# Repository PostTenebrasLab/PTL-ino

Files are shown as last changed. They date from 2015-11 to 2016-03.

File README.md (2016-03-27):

# PTL-ino

The PTL-ino (“petilino”) is a *uino-compatbile board that is fully made of easily solderable through-hole components.

You can find more general information at http://ptl-ino.com

The current Kicad file were made with Kicad 4.0.2, so please upgrade to Kicad 4 if you haven't already.
The Gerber file are there in case you simply want to order PCB directly to service like OSHPark or DirtyPCB.

If you plan to sell board based on this design, you have to remove our logo from the PCB.

PTL-ino board is licensed with Creative Common BY-SA 4.0 (https://creativecommons.org/licenses/by-sa/4.0/)

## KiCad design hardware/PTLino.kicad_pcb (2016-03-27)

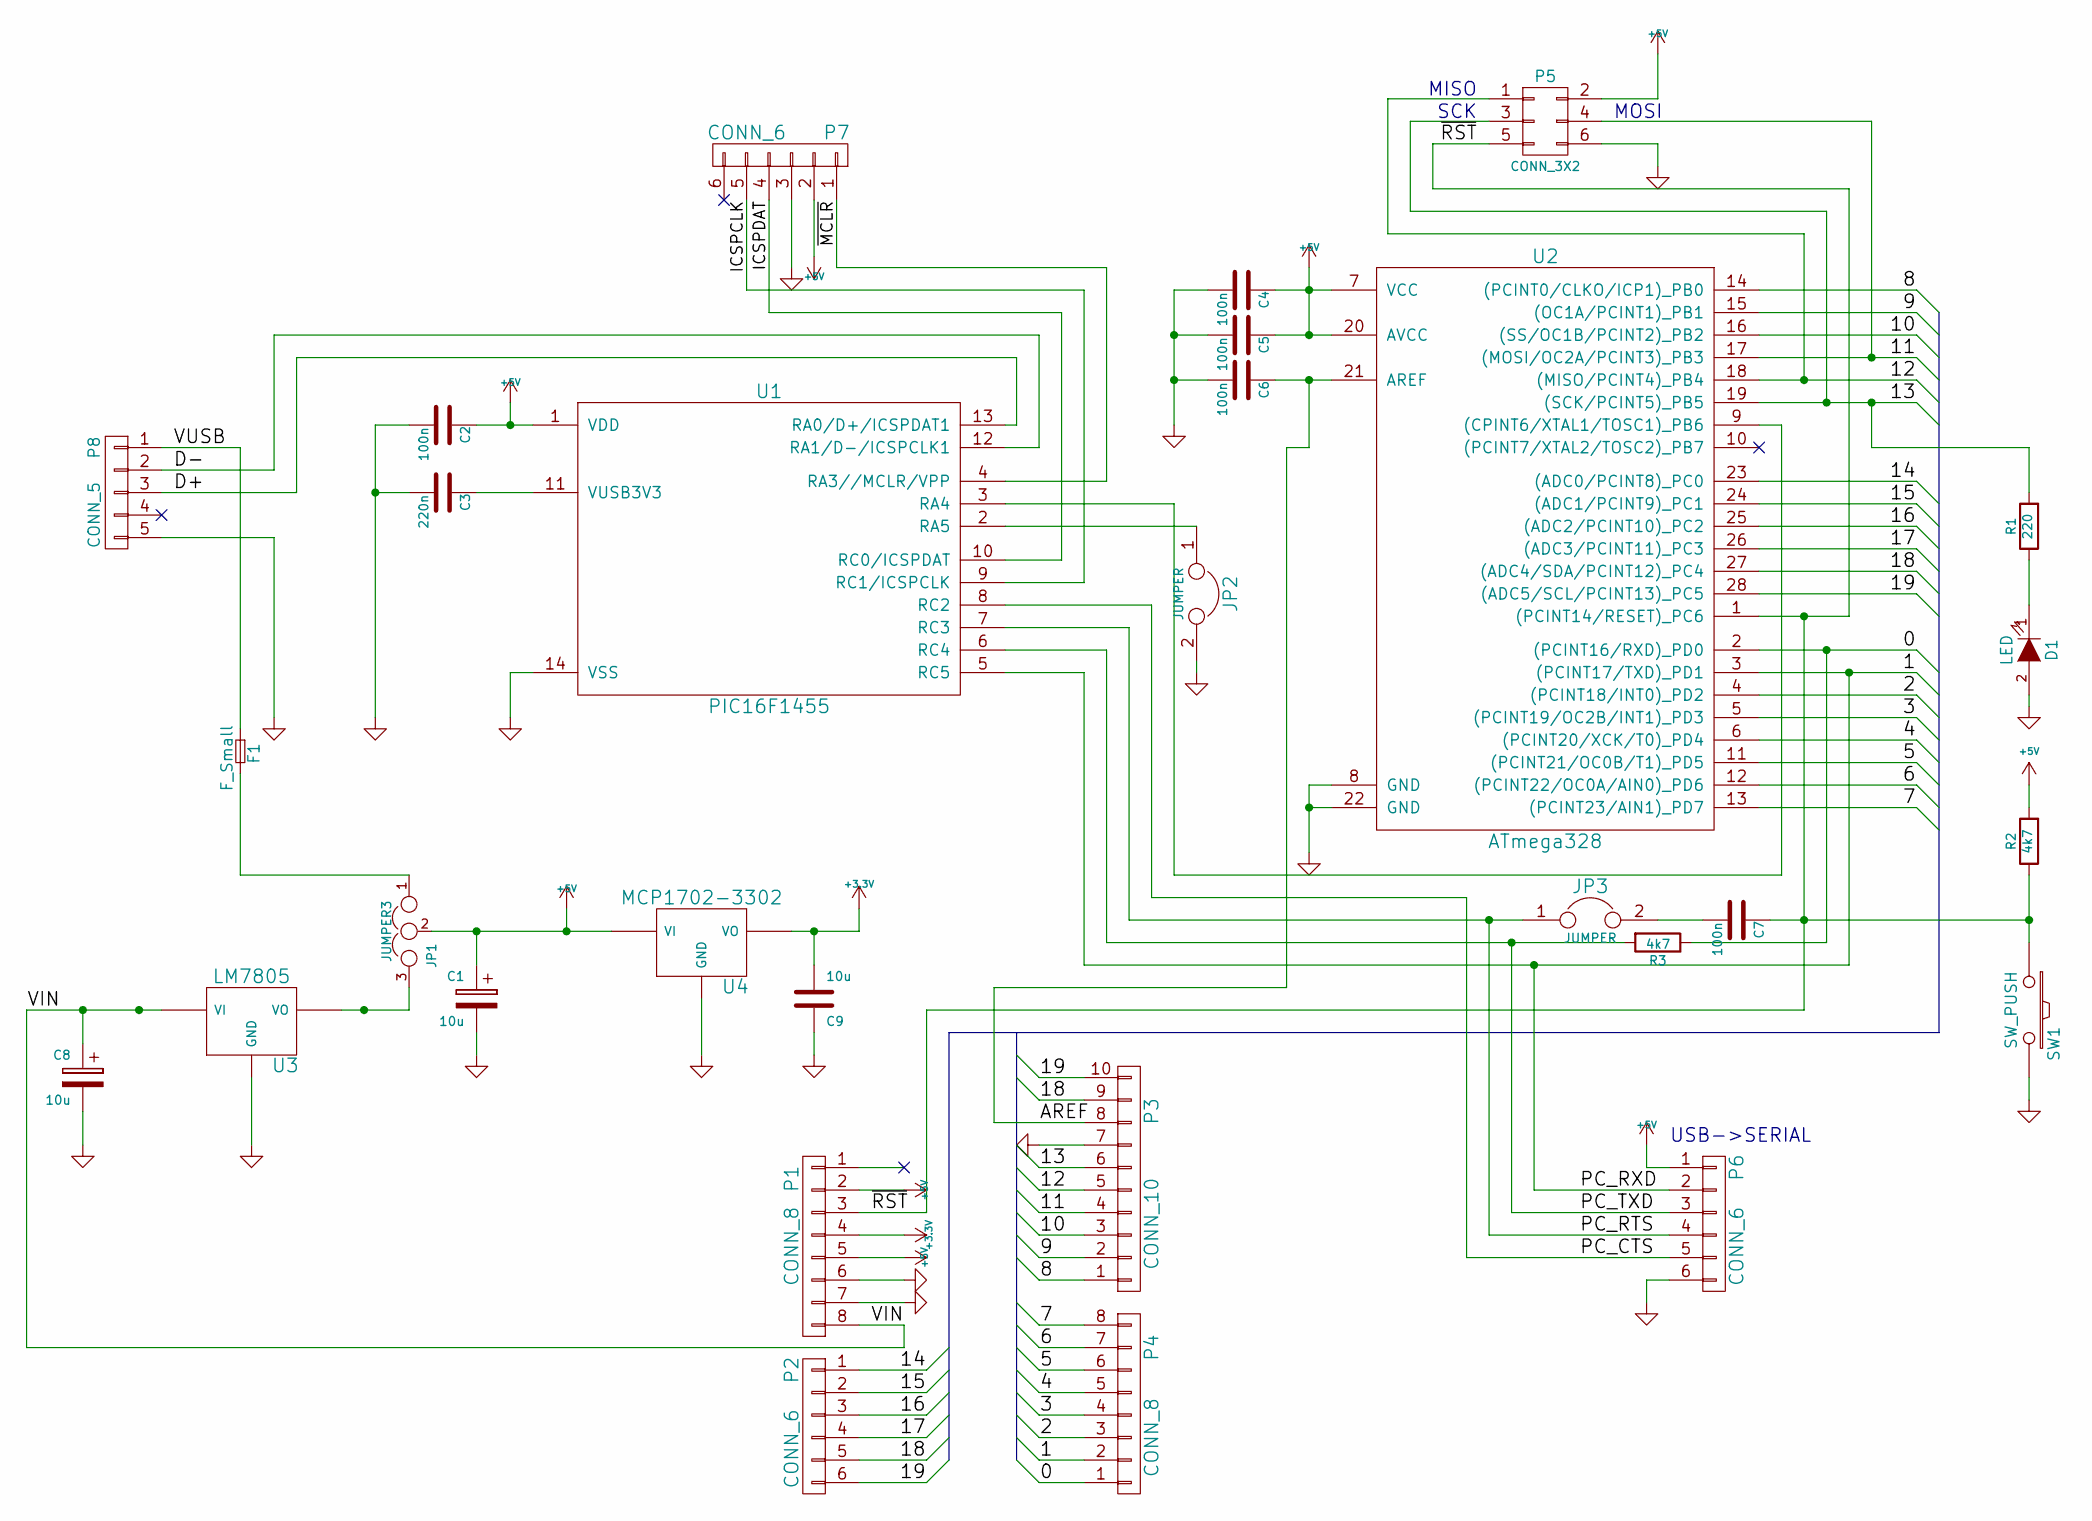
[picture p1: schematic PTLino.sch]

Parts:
C1, C8: 10u; C1V7H
C2, C4, C5, C6, C7: 100n; C1
C3: 220n; C1
C9: 10u; C1_pol
D1: LED; LEDV
F1: F_Small; F1
JP1: JUMPER3; solder-jumper-3
JP2, JP3: JUMPER; solder-jumper-2
P1, P4: CONN_8; SIL-8
P2, P6, P7: CONN_6; SIL-6
P3: CONN_10; SIL-10
P5: CONN_3X2; pin_array_3x2
P8: CONN_5; USB-mini-TH
R1: 220; R3-5
R2, R3: 4k7; R3-5
SW1: SW_PUSH; SW_PUSH_SMALL
U1: PIC16F1455; DIP-14__300_ELL
U2: ATmega328; DIP-28__300_ELL
U3: LM7805; TO220
U4: MCP1702-3302; TO92

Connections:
+3V3: C9.2, P1.4, U4.1 (VO)
+5V: C1.1, C2.1, C4.1, C5.1, JP1.2, P1.2, P1.5, P5.2, P6.1, P7.2, R2.2, U1.1 (VDD), U2.7 (VCC), U2.20 (AVCC), U4.2 (VI)
/0: P4.1, R3.1, U2.2 ((PCINT16/RXD)_PD0)
/1: P4.2, P6.2, U1.5 (RC5), U2.3 ((PCINT17/TXD)_PD1)
/2: P4.3, U2.4 ((PCINT18/INT0)_PD2)
/3: P4.4, U2.5 ((PCINT19/OC2B/INT1)_PD3)
/4: P4.5, U2.6 ((PCINT20/XCK/T0)_PD4)
/5: P4.6, U2.11 ((PCINT21/OC0B/T1)_PD5)
/6: P4.7, U2.12 ((PCINT22/OC0A/AIN0)_PD6)
/7: P4.8, U2.13 ((PCINT23/AIN1)_PD7)
/8: P3.1, U2.14 ((PCINT0/CLKO/ICP1)_PB0)
/9: P3.2, U2.15 ((OC1A/PCINT1)_PB1)
/10: P3.3, U2.16 ((SS/OC1B/PCINT2)_PB2)
/11: P3.4, P5.4, U2.17 ((MOSI/OC2A/PCINT3)_PB3)
/12: P3.5, P5.1, U2.18 ((MISO/PCINT4)_PB4)
/13: P3.6, P5.3, R1.2, U2.19 ((SCK/PCINT5)_PB5)
/14: P2.1, U2.23 ((ADC0/PCINT8)_PC0)
/15: P2.2, U2.24 ((ADC1/PCINT9)_PC1)
/16: P2.3, U2.25 ((ADC2/PCINT10)_PC2)
/17: P2.4, U2.26 ((ADC3/PCINT11)_PC3)
/18: P2.5, P3.9, U2.27 ((ADC4/SDA/PCINT12)_PC4)
/19: P2.6, P3.10, U2.28 ((ADC5/SCL/PCINT13)_PC5)
/AREF: C6.1, P3.8, U2.21 (AREF)
/D+: P8.3, U1.13 (RA0/D+/ICSPDAT1)
/D-: P8.2, U1.12 (RA1/D-/ICSPCLK1)
/ICSPCLK: P7.5, U1.9 (RC1/ICSPCLK)
/ICSPDAT: P7.4, U1.10 (RC0/ICSPDAT)
/PC_CTS: P6.5, U1.8 (RC2)
/PC_RTS: JP3.1, P6.4, U1.7 (RC3)
/PC_TXD: P6.3, R3.2, U1.6 (RC4)
/VIN: C8.1, P1.8, U3.2 (VI)
/VUSB: F1.1, P8.1
/~MCLR: P7.1, U1.4 (RA3//MCLR/VPP)
/~RST: C7.1, P1.3, P5.5, R2.1, SW1.1, U2.1 ((PCINT14/RESET)_PC6)
GND: C1.2, C2.2, C3.2, C4.2, C5.2, C6.2, C8.2, C9.1, D1.2 (A), JP2.2, P1.6, P1.7, P3.7, P5.6, P6.6, P7.3, P8.5, SW1.2, U1.14 (VSS), U2.8 (GND), U2.22 (GND), U3.3 (GND), U4.3 (GND)
unnamed: C3.1, U1.11 (VUSB3V3)
unnamed: C7.2, JP3.2
unnamed: D1.1 (K), R1.1
unnamed: F1.2, JP1.1
unnamed: JP1.3, U3.1 (VO)
unnamed: JP2.1, U1.2 (RA5)
unnamed: U1.3 (RA4), U2.9 ((CPINT6/XTAL1/TOSC1)_PB6)

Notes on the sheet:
MOSI
MISO
SCK
USB->SERIAL

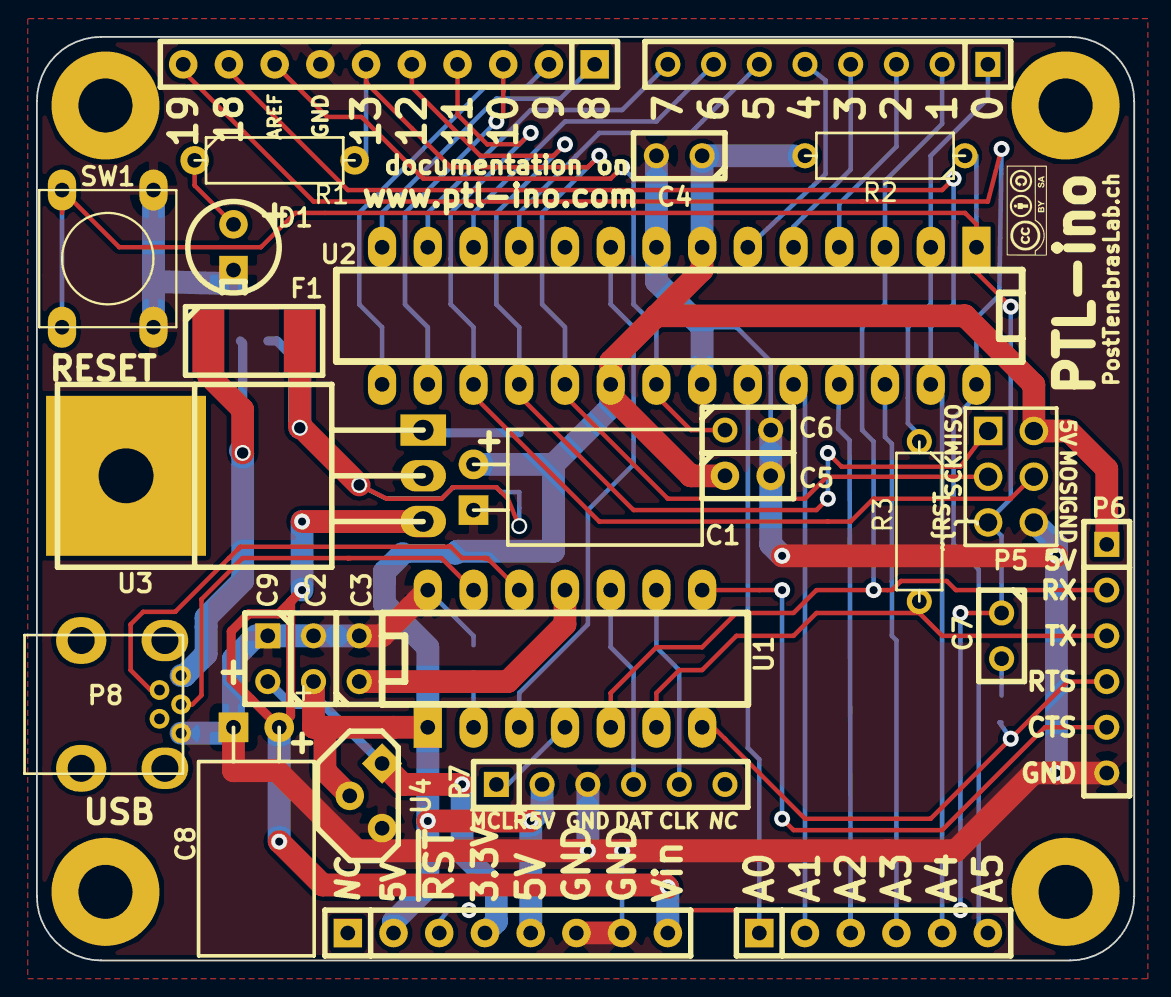
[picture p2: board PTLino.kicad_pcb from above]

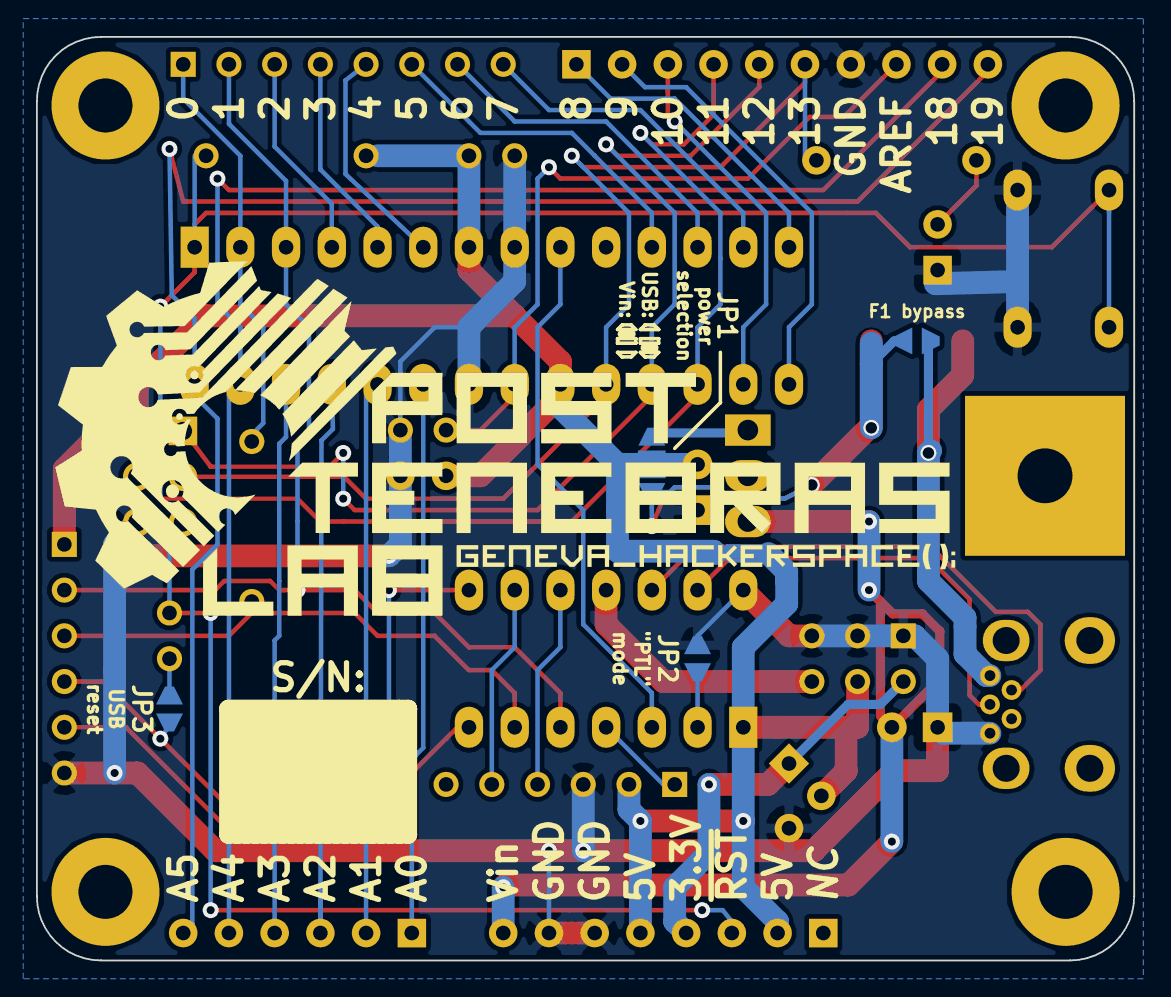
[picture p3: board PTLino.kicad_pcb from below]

Board: 2 copper layers, 61.0 x 51.3 mm, 35 parts (3 on the bottom side), 42 nets.

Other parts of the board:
CCBYSA: LOGO; Logo_silk_CC-BY-SA_5x2mm
mouting hole 3mm, mouting hole 3mm#2, mouting hole 3mm#3, mouting hole 3mm#4: VAL**; mounting-hole-3mm

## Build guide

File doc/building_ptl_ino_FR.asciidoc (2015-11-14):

//vim: set syntax=asciidoc:
//
//Generate HTML output with TOC on right side
//asciidoc --backend html5 -a max-width=57em -a toc2 -a toc-title="List of steps" -a numbered building_ptl_ino_FR.asciidoc
//
//Generate HTML slides (slidy backend)
//asciidoc --backend slidy -a max-width=57em -a toc2 -a toc-title="List of steps" -a numbered building_ptl_ino_FR.asciidoc
//

// 
//**********************************************************************
//Work in progress PTL-ino doc using Ascidoc
//**********************************************************************
//

:Author:    Post Tenebras Lab
:Date:      2015-11
:Revision:  1.0
:Language:  French
:website:   http://ptl-ino.com/

Comment assembler la PTL-ino 
============================

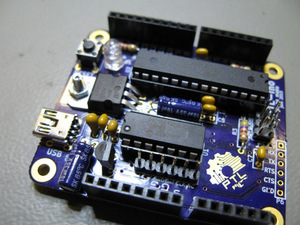
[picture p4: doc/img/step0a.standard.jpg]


.Liste des outils nécessaires

  * Fer à Souder 
  * Fil de soudure 
  * Pince coupante
  * Multimètre

.Liste des composants

Tous les composants ci-dessous sont inclus dans le kit PTL-ino.

.Condensateur
[options="header",width="70%",cols="^1,^5m,^3e"]
|=======================
| Qty |Name |Label
| 5x |100nF ceramic | C2, C4, C5, C6, C7
| 5x |220nF tantal | C3
| 1x |10uF ceramic | C1, C8
| 2x |10uF Felectrolytic | C9
|=======================

.Resistance
[options="header",width="70%",cols="^1,^5m,^3e"]
|=======================
| Qty |Name |Label
| 2x |4.7kΩ | R2, R3
| 1x |220Ω | R1
|=======================

.Semiconducteurs
[options="header",width="70%",cols="^1,^5m,^3e"]
|=======================
| Qty |Name |Label
| 1x |LED, 5mm (any colour) | D1
| 1x |LM7805 | U3
| 1x |MCP1700 | U4 
| 1x |PIC 16F1455 | U1
| 1x |AVR ATmega328P | U2
|=======================

.Mécanique
[options="header",width="70%",cols="^1,^5m,^3e"]
|=======================
| Qty |Name |Label
| 2x |1x8 2.54mm female connector | P1, P4
| 1x |1x6 2.54mm female connector | P2
| 1x |1x10 2.54mm female connector | P3
| 1x |2x3 2.54mm male connector | P5
| 2x |1x6 2.54mm male connector | P6, P7
| 1x |2x7 2.54 IC socket, DIL-14 | U1
| 1x |2x14 2.54mm IC socket, DIL-28 | U2
| 1x |USB mini female connector | P8
| 1x |push-button | SW1
| 1x |PCB | - 
| 1x |mini-USB cable | -
|=======================

== Préparez vos composants et alignez les ==

* Vérifiez que votre kit est complet et corresponde à la liste des composants indiqués
* Organisez vos composants pour pouvoir facilement les retrouver

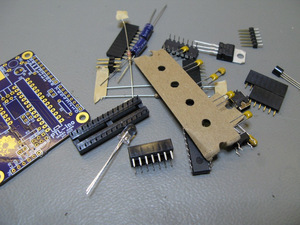
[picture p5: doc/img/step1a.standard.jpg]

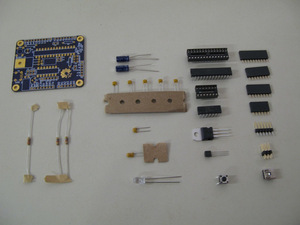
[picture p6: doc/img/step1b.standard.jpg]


== Installer les résistances ==

* Commencez avec la résistance 'R1'. C'est celle avec les couleurs rouge-rouge-marron-doré. L'orientation n'est pas importante pour ce composant.
* Placez 'R2' et 'R3' à leurs places respectives, elles ont les couleurs jaune-violet-rouge-doré. L'orientation n'est pas non plus importante pour ces composant.
* Tourner le PCB et soudez les 3 résistances en place.
* Une fois terminé avec la soudure, coupez le surplus des pattes(fil) des résistances.

TIP: Afin de garder les composants en place quand vous tournez le PCB, vous pouvez plier les pattes à 45 degrés.

TIP: Quand vous coupez le surplus de fil, portez des lunettes de protection ou tenez le bout de fil avec les mains.

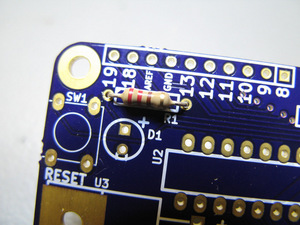
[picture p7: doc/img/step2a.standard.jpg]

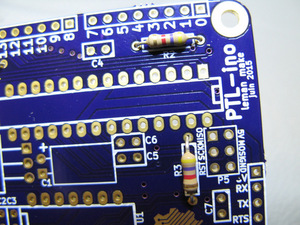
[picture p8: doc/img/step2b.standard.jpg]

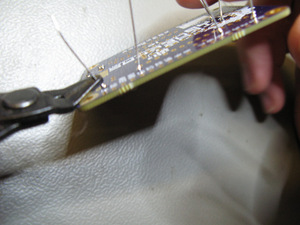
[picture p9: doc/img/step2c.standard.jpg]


== Installer les supports IC ==

* Placer les 2 socles pour CI ('U1', 'U2'). Ils ont un encoche, qui doit être du même côté que le marquage sur le PCB.
* Tournez le PCB et faites la soudure. Vous pouvez utiliser un ruban adhésif pour les garder en place.
* Il n'y a pas besoin de couper les pattes du support après la soudure car ils ont déjà la bonne taille.

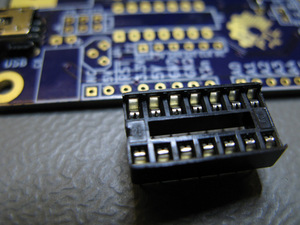
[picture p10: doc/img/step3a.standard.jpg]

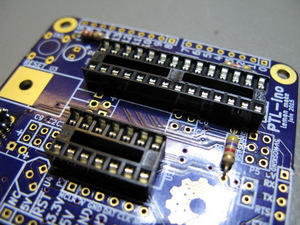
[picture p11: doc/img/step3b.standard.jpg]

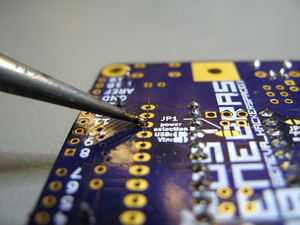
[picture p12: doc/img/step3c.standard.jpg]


==  Bouton reset ==

* Placez le bouton reset ('SW1').
* Orientation of the switch does not matter.

NOTE: Il faut forcer un peu pour installer le bouton, les pattes doivent être légèrement pliée. Il y aura toujours un espace entre le bouton et la surface du PCB.

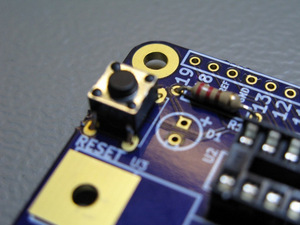
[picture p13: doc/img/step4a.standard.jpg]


==  Condensateurs  ==

* Placez le condensateur 'C3' de 220nF (écrit 224 sur le composant). Il n'y a pas de polarité pour ce composant.
* Placez 'C2', 'C4', 'C5', 'C6' et 'C7' de 100nF. Ils sont tous les mêmes avec 104 écrit dessus. Il n'y a pas de polarité pour ces composants.
* 'C9' est le condensateur tantale, *la polarité EST importante*. Il faut aligner la signe '+' indiqué sur le composant avec la signe '+' indiqué sur le PCB.

WARNING: Le condasateur tantale va exploser si la polarité n'est pas correcte. Verifier bien le sens.

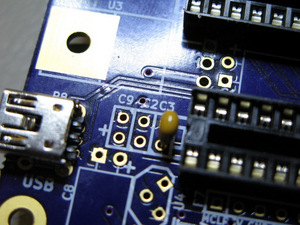
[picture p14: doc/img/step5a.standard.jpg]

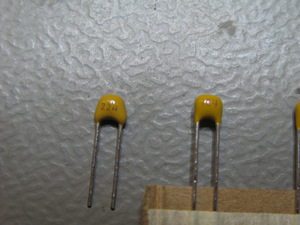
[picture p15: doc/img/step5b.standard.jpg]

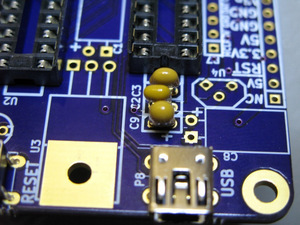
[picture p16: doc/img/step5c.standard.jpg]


==  Régulateur 5V ==

* Placez le régulateur 5V ('U3') et alignez le trou avec le trou sur le PCB.
* Faites la soudure et coupez les pattes(fil) en plus.

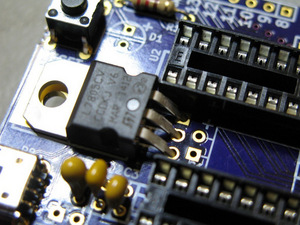
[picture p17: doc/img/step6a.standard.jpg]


== Condensateurs électrolytiques ==

* Placez les 2 condensateurs électrolytiques ('C1' et 'C8'). Pliez les de façon qu'ils soient à plat sur le PCB (voir photo)
* Sur le PCB il y'a un marquage avec le signe '+' et sur le condensateurs il y'a un marquage avec le signe '-' (en blanc). Ces 2 signes doivent s'opposer quand vous placez les composants.

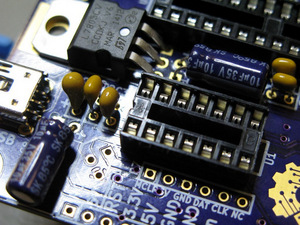
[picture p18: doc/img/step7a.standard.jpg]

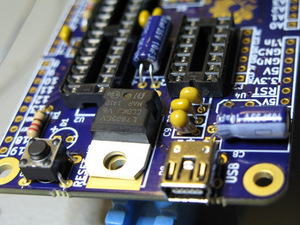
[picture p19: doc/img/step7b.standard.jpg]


== Régulateur 3.3V ==

* Placez le régulateur 3.3V LM1700 ('U4'). La forme sur le PCB doit correspondre avec la forme du régulateur.
* Il va falloir plier un tout petit peu la patte du milieu pour l'enfiler dans les trous du PCB.

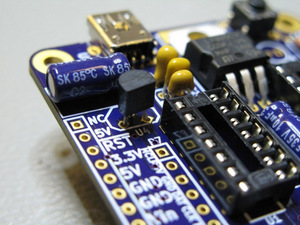
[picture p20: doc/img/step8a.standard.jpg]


== LED ==

* Placez la LED ('D1'). *La patte longue doit aller sur le + indiqué sur la PCB.*

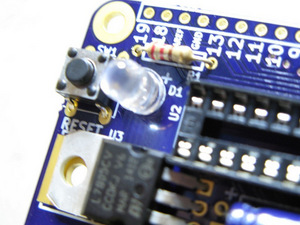
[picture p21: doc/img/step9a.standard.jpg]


== Connecteurs mâles ==

* Placez les connecteurs mâles 1x6 ('P7') et 2x3 ('P5'). Tournez le PCB et faites la soudure.
* Du ruban adhésif peut être utilisé pour les garder en place pendant la soudure.

NOTE: Voir l'image pour le placement correcte. Ces pièces n'ont pas d'orientation.

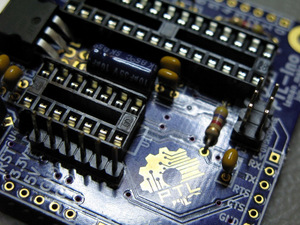
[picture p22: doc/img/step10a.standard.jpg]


== Connecteurs femelles ==

* Placez les connecteurs femelles ('P1', 'P2', 'P3', 'P4'). Il faut faire seulement la soudure de la première et dernière patte.
* Après les 2 soudures, il faut s'assurer que les connecteurs sont bien perpendiculaire au PCB. Sinon, il faut rechauffer une des soudure et pousser le connecteur d'un côté; puis refaire la même chose de l'autre côté.
* Une fois que le connecteur est parfaitement perpendiculaire, vous pouvez continuer à souder les restes des pattes.

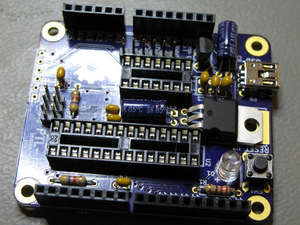
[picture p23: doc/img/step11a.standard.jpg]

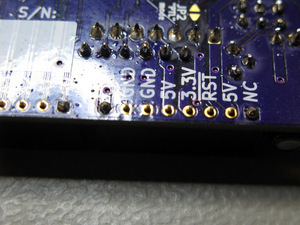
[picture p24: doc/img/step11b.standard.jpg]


== Micro-controlleurs ==

* Pour placer les microcontrolleurs ('U1', 'U2') dans leur support, il faut plier les pattes afin qu'elles soient droites. Pour faire ça, vous pouvez le mettre sur la table sur le coté et appuyer gentiment pour plier toutes les pattes d'un coté en même temps.
* Il faut bien placer les microcontrolleurs afin que le petit point sur l'IC corresponde avec le marquage sur le PCB et l'encoche du support.

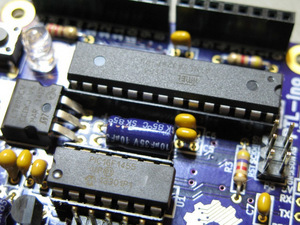
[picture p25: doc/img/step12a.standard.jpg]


== Visser le régulateur 5V ==

* Mettez un vis et un écrou M3 pour fixer le régulateur 5V en place.
* La vis est utilisée pour faciliter le contact thermique avec le PCB au cas ou le régulateur chauffe

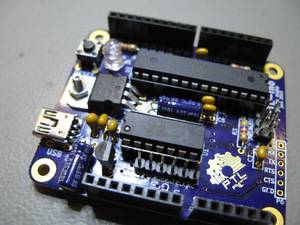
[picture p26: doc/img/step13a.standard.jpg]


== Connecteur mini-USB ==

* Placez le connecteur mini-USB ('P8') et soudez les 2 (ou 4) pattes du blindage.
* Puis soudez les 5 pins pour l'alimentation et données. Faite attention de ne pas faire des "ponts" puisque ces pattes sont très proches et petites.

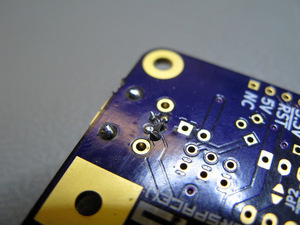
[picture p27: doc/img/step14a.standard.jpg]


== Configuration des jumpers/ponts ==

* Sur le dos du PCB, il y'a un "jumper/cavalier" (le jumper est un composant qui permet de relier deux broches). 
* Il faut faire une soudure sur 'JP1' entre le les 2 points selon le marquage indiqué sur la PCB (soit alimenté en USB soit alimenté avec l'entrée Vin)
* Il faut également souder le 'JP3' pour activer le "auto-reset" qui permet de programmer la PTL-ino avec les outils Arduino

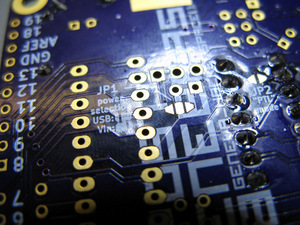
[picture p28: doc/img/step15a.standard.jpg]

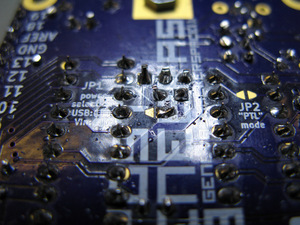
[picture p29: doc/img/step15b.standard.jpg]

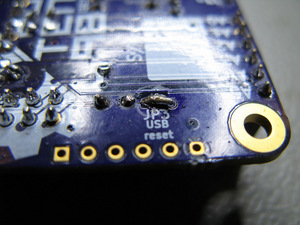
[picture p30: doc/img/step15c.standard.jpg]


//== Note ==
//
//[qanda]
//.Q&A
//Question 1::
//    Answer 1
//
//Question 2:: 
//    Answer 2
//
//CPU:: The brain of the computer.
//Hard drive:: Permanent storage for operating system and/or user files.
//RAM:: Temporarily stores information the CPU uses during operation.
//Keyboard:: Used to enter text or control items on the screen.
//Mouse:: Used to point to and select items on your computer screen.
//Monitor:: Displays information in visual form using text and graphics.

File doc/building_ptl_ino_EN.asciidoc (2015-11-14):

//vim: set syntax=asciidoc:
//
//Generate HTML output with TOC on right side
//asciidoc --backend html5 -a max-width=57em -a toc2 -a toc-title="List of steps" -a numbered building_ptl_ino_EN.asciidoc
//
//Generate HTML slides (slidy backend)
//asciidoc --backend slidy -a max-width=57em -a toc2 -a toc-title="List of steps" -a numbered building_ptl_ino_EN.asciidoc
//

// 
//**********************************************************************
//Work in progress PTL-ino doc using Ascidoc
//**********************************************************************
//

:Author:    Post Tenebras Lab
:Date:      2015-11
:Revision:  1.0
:Language:  English
:website:   http://ptl-ino.com/

How to build a PTL-ino board
============================

.About the PTL-ino

The PTL-ino is an Arduino compatible board, made entirely out of through-hole components. It is a perfect project to learn how to solder and start getting into the world of micro controllers.



.List of tools needed

  * Soldering iron
  * Solder
  * Wire cutter
  * Multimeter

.List of componants

Everything listed bellow is included in the PTL-ino kit

.Capactitors
[options="header",width="70%",cols="^1,^5m,^3e"]
|=======================
| Qty |Name |Label
| 5x |100nF ceramic | C2, C4, C5, C6, C7
| 5x |220nF tantal | C3
| 1x |10uF ceramic | C1, C8
| 2x |10uF Felectrolytic | C9
|=======================

.Resistors
[options="header",width="70%",cols="^1,^5m,^3e"]
|=======================
| Qty |Name |Label
| 2x |4.7kΩ | R2, R3
| 1x |220Ω | R1
|=======================

.Semiconductors
[options="header",width="70%",cols="^1,^5m,^3e"]
|=======================
| Qty |Name |Label
| 1x |LED, 5mm (any colour) | D1
| 1x |LM7805 | U3
| 1x |MCP1700 | U4 
| 1x |PIC 16F1455 | U1
| 1x |AVR ATmega328P | U2
|=======================

.Mechanical
[options="header",width="70%",cols="^1,^5m,^3e"]
|=======================
| Qty |Name |Label
| 2x |1x8 2.54mm female connector | P1, P4
| 1x |1x6 2.54mm female connector | P2
| 1x |1x10 2.54mm female connector | P3
| 1x |2x3 2.54mm male connector | P5
| 2x |1x6 2.54mm male connector | P6, P7
| 1x |2x7 2.54 IC socket, DIL-14 | U1
| 1x |2x14 2.54mm IC socket, DIL-28 | U2
| 1x |USB mini female connector | P8
| 1x |push-button | SW1
| 1x |PCB | - 
| 1x |mini-USB cable | -
|=======================

== Get all the components ready ==

* Check that the kit contains all the components.
* Arrange the components so you can easily find them.




== Populate the resistors ==

* Start with resistor 'R1'. It is the one with red-red-brown-gold rings. Orientation is not important.
* Then 'R2' and 'R3'. They are the one with yellow-violet-red-gold rings and once again, the orientation is not important.
* After placing the 3 resistors, turn the board over to solder them in place.
* Then, cut off the extra bits of wire  sticking out of the PCB (shorten the "legs" of the resistors).

TIP: To keep the components in place when you flip the board to do the soldering, you can bend the wires in 45 degrees.

TIP: When cutting extra wires, make sure you either wear a protective goggle or that you hold the extra pice with your other hand.





== Populate the IC sockets ==

* Populate the 2 IC sockets ('U1', 'U2'). They have a small notch, that should be on the same side as the small markings on the PCB.
* Turn over the board and solder the 2 IC sockets. You can use masking tape to keep the sockets in place when you turn the board.
* The sockets fit perfectly and there is no need to cut any extra "wires"





== Populate the reset switch ==

* Insert the switch ('SW1') and solder it.
* Orientation of the switch does not matter.

NOTE: Note that you will have to force it a little bit to make it a tight fit. Also, it is normal to have a small space between the board and the switch.



== Populate the capacitors ==

* Put 'C3' in place. 'C3' is the 220nF with 224 written on it. Polarity is not important for this component.
* Put 'C2', 'C4', 'C5', 'C6' and 'C7'. These are all the same, and are 100nF with 104 written on it. Polarity is not important for these components.
* 'C9' is the tantalum capacitor, and **the polarity IS important**. You have to match the side with the '+' sign on the capacitor, with the '+' sign on the PCB.

WARNING: Tantalum capacitor will explode if the polarity is incorrect. Please double check.





== Populate the 5V regulator ==

* Insert the 5V regulator ('U3'), and align the hole on the PCB with the hole on the component.
* You can cut the extra leads



== Populate the electrolytic capacitors ==

* Put the 2 electrolytic capacitors ('C1' and 'C8') in place. Bend them so they lie on the PCB as shown in the picture.
* On the PCB there is a '+' sign, and one side of the capacitor has a stripe with a '-' sign. The '-' sign should be on the opposite side to the '+' sign.




== Populate the 3.3V regulator ==

* Insert the LM1700 3.3V regulator ('U4'). The marking on the PCB matches the shape of the component; so that the flat part of the regulator matches the straight line on the board.
* You will have to bend the middle lead a little bit in order for it to fit.
* You can cut the extra leads when done with soldering.



== Populate the LED ==

* Put the LED ('D1') in place. The longer lead goes where the '+' marking is on the PCB.
* You can cut the extra leads after soldering.



== Populate the male headers ==

* Put the 1x6 **male header** ('P7') and 2x3 **male header** ('P5') in their holes and solder them. Masking tape can help to keep them in place.
* Check the picture for the correct position. There is no orientation for headers.



== Populate the female headers ==

* Put the **female headers** ('P1', 'P2', 'P3', 'P4') in place. When you solder them, first solder just the 2 extremities.
* After soldering the 2 outer pins of the 4 headers, check that the headers are perfectly perpendicular to the PCB. If not, simply heat one of the soldered pads and push the header flat to the PCB.

NOTE: Having the header perfectly perpendicular will make it easy to add "Shields" to your board, otherwise adding a shield will require you to bend the leads




== Populate the micro controllers ==

* To insert the micro controller ('U1', 'U2'), you have to gently bend the pins so they are really straight. The best option is to slowly push the chip on one side, bending the pins on the table.
* The micro controller has an orientation. Find the small dot and marking on one side, it should match with the marking on the PCB and the IC socket.



== Screw the 5V regulator to PCB ==

* Screw the 5V regulator to the PCB using the M3 screw and nut.
* The screw and nut are used to make a better contact with the board to dissipate heat. It is not used in the electronic circuit.



== Populate the mini-USB connector ==

* Insert the mini-USB connector ('P8') and start soldering the 2 (or 4) leads of the connector shield.
* Solder the 5 pins for the USB power and signal



== Solder the jumper/bridge on the back-side ==

* Solder the jumper 'JP1'. Read the marking on the PCB to decide if powering should come from USB or Vin pin.
* Solder jumper 'JP3' to have the auto-reset feature needed to program with the Arduino IDE:





//== Note ==
//
//[qanda]
//.Q&A
//Question 1::
//    Answer 1
//
//Question 2:: 
//    Answer 2
//
//CPU:: The brain of the computer.
//Hard drive:: Permanent storage for operating system and/or user files.
//RAM:: Temporarily stores information the CPU uses during operation.
//Keyboard:: Used to enter text or control items on the screen.
//Mouse:: Used to point to and select items on your computer screen.
//Monitor:: Displays information in visual form using text and graphics.

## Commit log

2015-11-14 Added our doc on how to build the ptl-ino kit (FR + EN) This is a conversion of current doc to ASCIIDOC format. ptl.dozuki.com/Guide/How+to+build+a+PTL-ino+board/
2015-11-17 Added the windows "driver" (.inf file to indicate device is standard serial USB)
2016-03-27 updated to latest version of PTL-ino (v2) and added a template for doing PTL-ino shield.
    [PTLino.kicad_pcb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]
2016-03-27 Added a few pictures, and clarified the use of our logo in case of commercial usage.
2016-03-28 Added meta dir to kicad shield template
